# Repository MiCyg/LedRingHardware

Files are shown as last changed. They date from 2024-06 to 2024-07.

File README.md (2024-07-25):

# LedRingHardware

## Description

LedRingHardware is a simple PCB devBoard based on the RP2040 microcontroller, featuring 8 programmable LEDs and battery supply. This project was created to explore the capabilities of MicroPython and CircuitPython.

## Visualization
<p align="center">
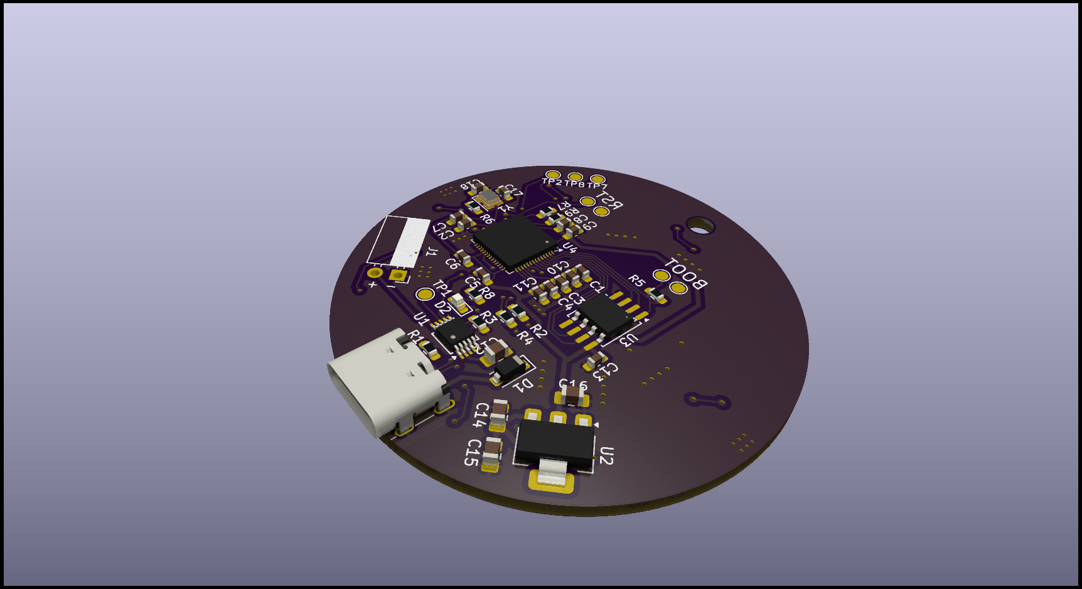
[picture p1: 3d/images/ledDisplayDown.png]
LED Display Bottom View
  
&nbsp; &nbsp; &nbsp; &nbsp;
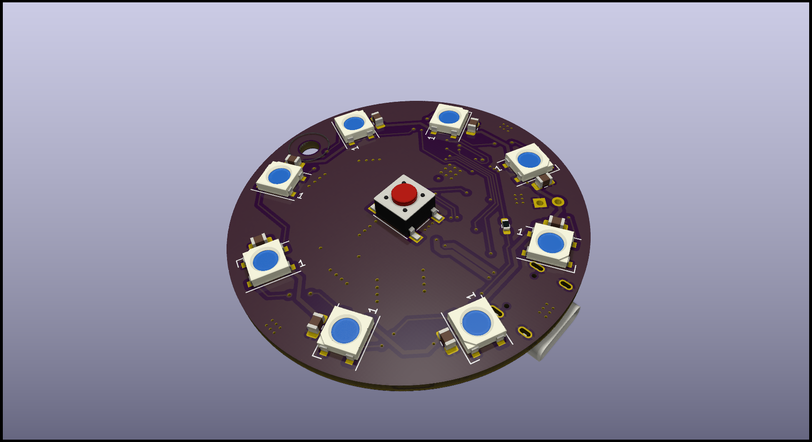
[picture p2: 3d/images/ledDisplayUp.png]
LED Display Top View
  
</p>

## Installation

- Enter to **BOOTSEL** mode connect **boot** testpoints placed close to **U3** chip.
- Download CircuitPython firmware for rp2040. There is avaliable [here](https://downloads.circuitpython.org/bin/raspberry_pi_pico/pl/adafruit-circuitpython-raspberry_pi_pico-pl-9.1.1.uf2) or for latest version go to [CircuitPython](https://circuitpython.org/) site.
- Copy `.uf2` firmware to device

## Example code

```python

import board
import time
import neopixel

LED_NUMBER = 8
BUTTON_PIN = board.GP22
LED_PIN = board.GP13

COLOR = (10,0,15)
disp_pix = neopixel.NeoPixel(LED_PIN, LED_NUMBER, auto_write=False)

while True:
	for i in range(LED_NUMBER):
		disp_pix[i] = COLOR
		disp_pix.show()
		time.sleep(0.1)
		
	for i in range(LED_NUMBER):
		disp_pix[i] = (0,0,0)
		disp_pix.show()
		time.sleep(0.1)
```

Expected results will be that:

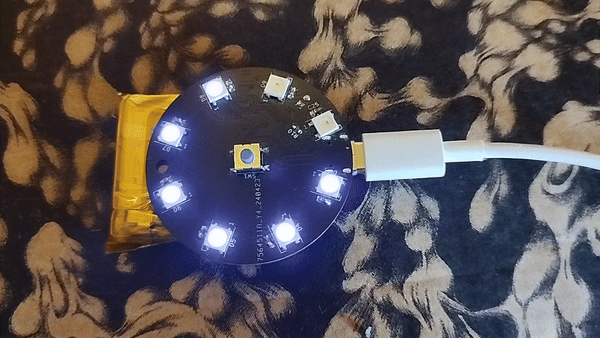
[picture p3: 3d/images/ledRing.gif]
LedRing working Example


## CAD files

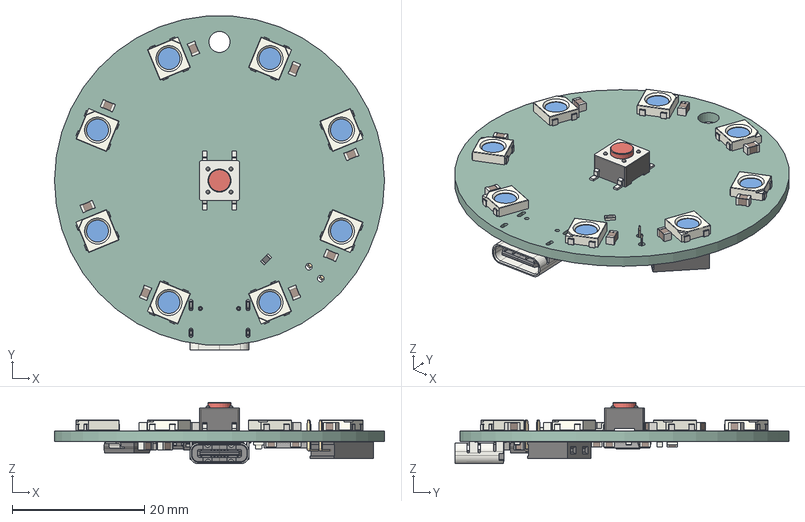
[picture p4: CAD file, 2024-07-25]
3d/ledDisplay.step
50.0 x 50.6 x 9.31 mm
C_0805_2012Metric x 12
LED_WS2812B_PLCC4_50x50mm_P32mm x 8
SW_SPST_PTS645
R_0603_1608Metric x 10
C_0603_1608Metric x 14
Crystal_SMD_2520-4Pin_2.5x2.0mm
MSOP_10_3x3mm_P05mm
HTSOP_8_1EP_39x49mm_Pitch127mm
LED_0603_1608Metric
D_SOD_123
PinSocket_1x02_P254mm_Horizontal
SOT_223
USB_C_Receptacle_16P_TopMnt_Horizontal_GCT_USB4105-xx-A
QFN_56_1EP_7x7mm_P04mm_EP32x32mm
ledDisplay_PCB

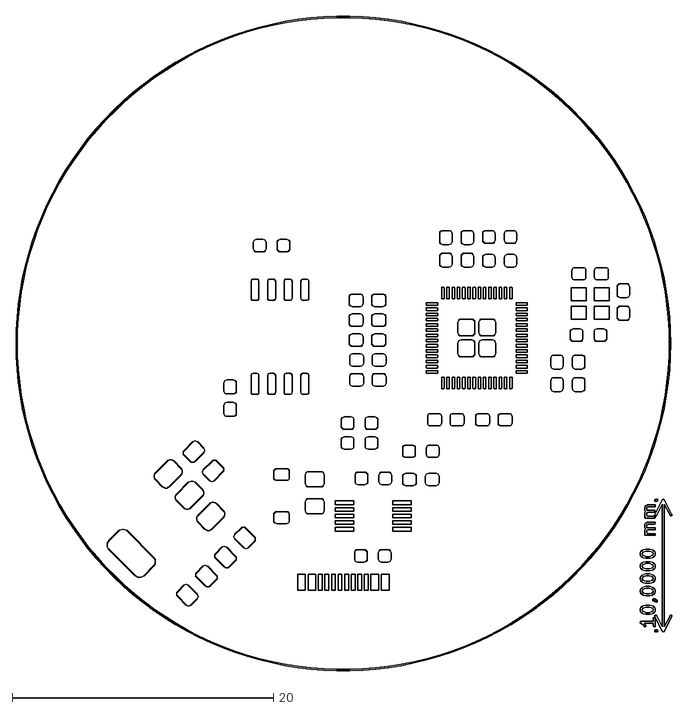
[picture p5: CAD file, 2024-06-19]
gerber/mask/ledDisplay-Edge_Cuts.dxf
50.2 x 50.1

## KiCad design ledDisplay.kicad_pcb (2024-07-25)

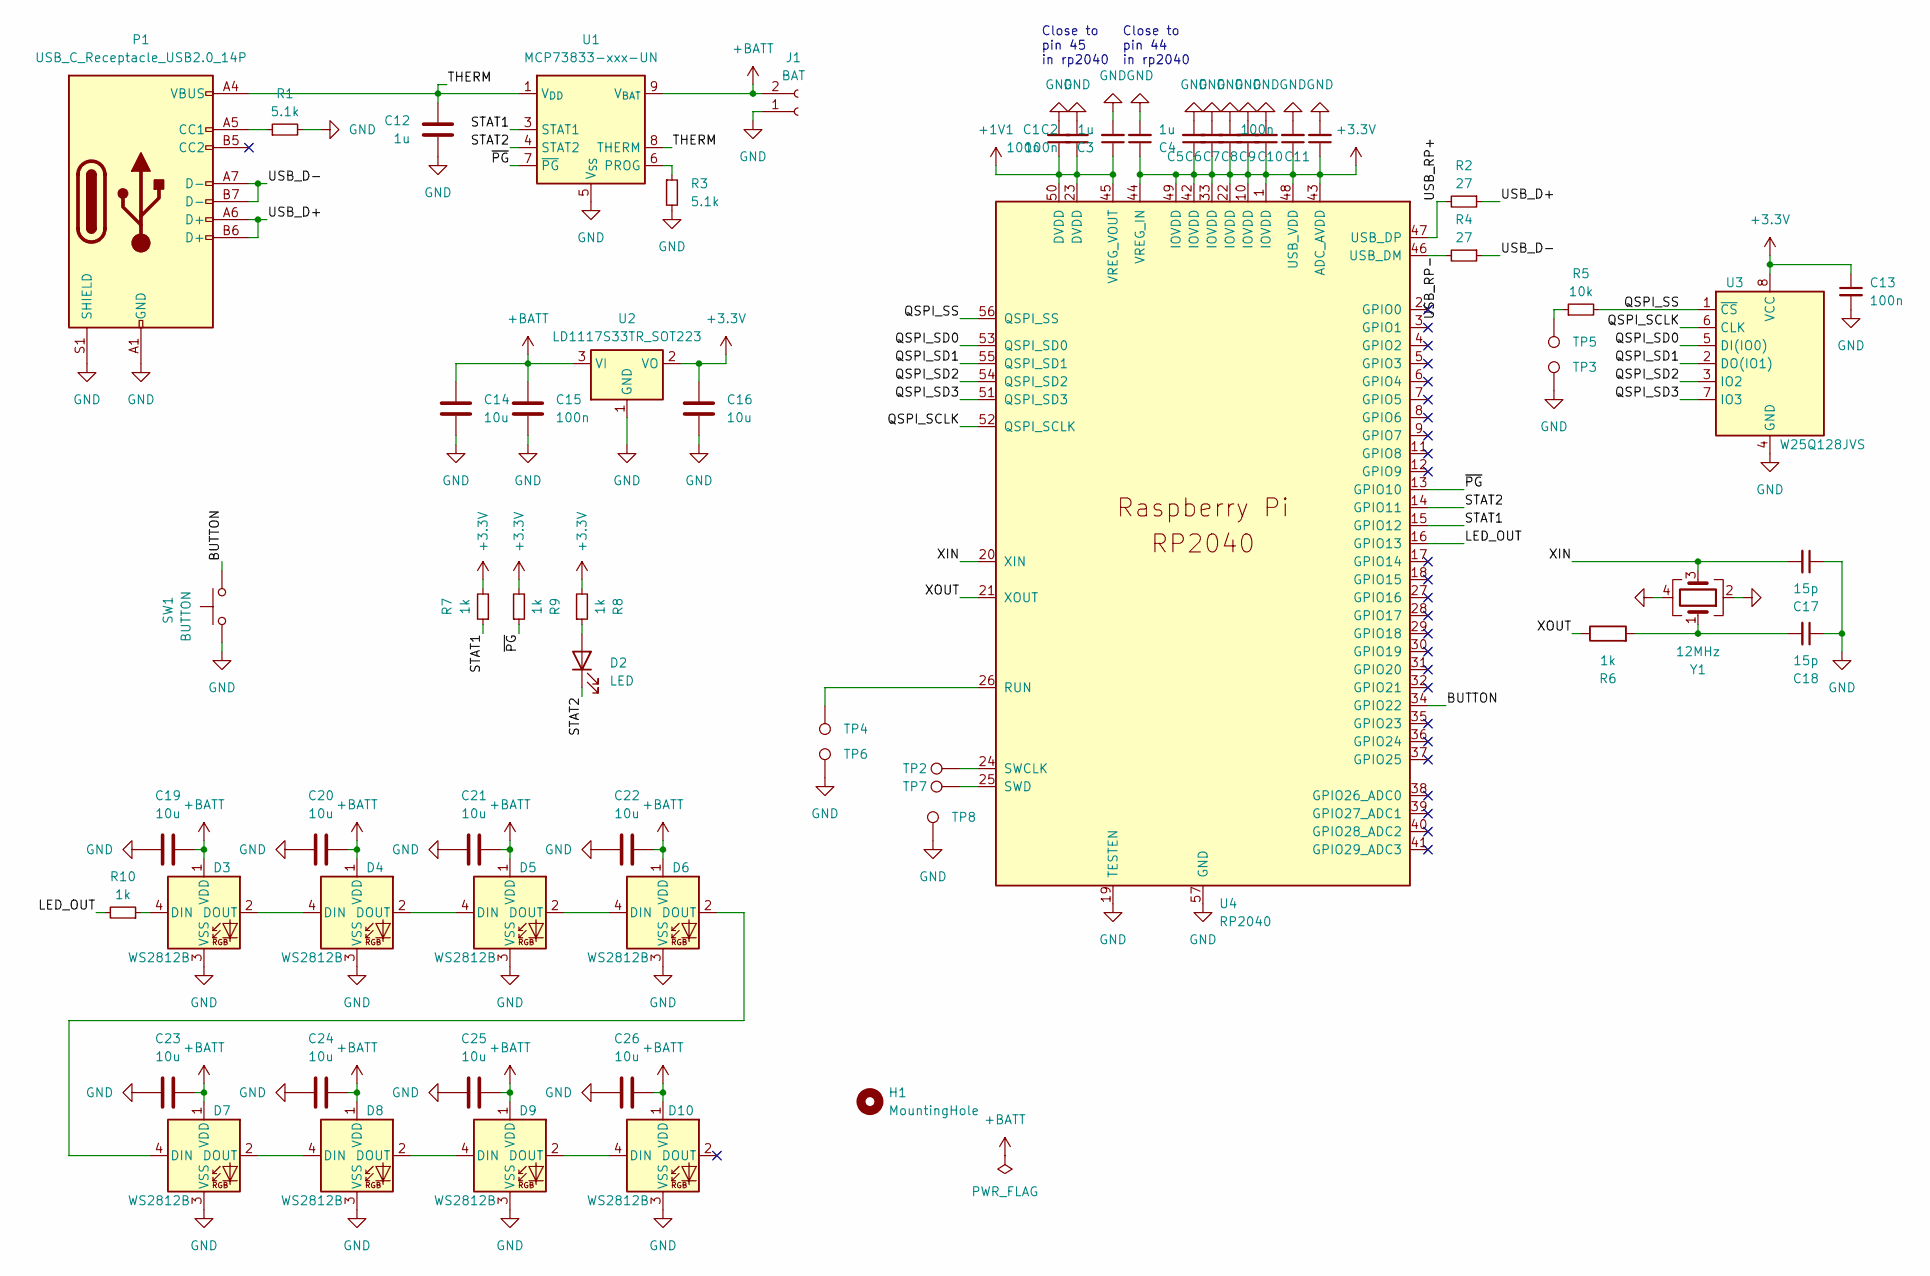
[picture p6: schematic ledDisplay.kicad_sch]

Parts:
C1, C2, C5, C6, C7, C8, C9, C10, C11, C13: 100n; C_0603_1608Metric_Pad1.08x0.95mm_HandSolder
C3, C4: 1u; C_0603_1608Metric_Pad1.08x0.95mm_HandSolder
C12: 1u; C_0805_2012Metric_Pad1.18x1.45mm_HandSolder
C14, C16, C19, C20, C21, C22, C23, C24, C25, C26: 10u; C_0805_2012Metric_Pad1.18x1.45mm_HandSolder
C15: 100n; C_0805_2012Metric_Pad1.18x1.45mm_HandSolder
C17, C18: 15p; C_0603_1608Metric_Pad1.08x0.95mm_HandSolder
D2: LED; LED_0603_1608Metric_Pad1.05x0.95mm_HandSolder
D3, D4, D5, D6, D7, D8, D9, D10: WS2812B; LED_WS2812B_PLCC4_5.0x5.0mm_P3.2mm
H1: MountingHole; MountingHole_3.2mm_M3
J1: BAT; PinSocket_1x02_P2.54mm_Horizontal
P1: USB_C_Receptacle_USB2.0_14P; USB_C_Receptacle_G-Switch_GT-USB-7010ASV
R1, R3: 5.1k; R_0603_1608Metric_Pad0.98x0.95mm_HandSolder
R2, R4: 27; R_0603_1608Metric_Pad0.98x0.95mm_HandSolder
R5: 10k; R_0603_1608Metric_Pad0.98x0.95mm_HandSolder
R6, R7, R8, R9, R10: 1k; R_0603_1608Metric_Pad0.98x0.95mm_HandSolder
SW1: BUTTON; SW_Push_1P1T_NO_6x6mm_H9.5mm
TP2, TP3, TP4, TP5, TP6, TP7, TP8: TestPoint; TestPoint_Pad_D1.5mm
U1: MCP73833-xxx-UN; MSOP-10_3x3mm_P0.5mm
U2: LD1117S33TR_SOT223; SOT-223-3_TabPin2
U3: W25Q128JVS; SOIC-8_5.23x5.23mm_P1.27mm
U4: RP2040; RP2040-QFN-56
Y1: 12MHz; Crystal_SMD_SeikoEpson_TSX3225-4Pin_3.2x2.5mm_HandSoldering

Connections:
+1V1: C1.1, C2.1, C3.1, U4.23 (DVDD), U4.45 (VREG_VOUT), U4.50 (DVDD)
+3.3V: C4.1, C5.1, C6.1, C7.1, C8.1, C9.1, C10.1, C11.1, C13.1, C16.1, R7.2, R8.2, R9.2, U2.2 (VO), U3.8 (VCC), U4.1 (IOVDD), U4.10 (IOVDD), U4.22 (IOVDD), U4.33 (IOVDD), U4.42 (IOVDD), U4.43 (ADC_AVDD), U4.44 (VREG_IN), U4.48 (USB_VDD), U4.49 (IOVDD)
+BATT: C14.1, C15.1, C19.1, C20.1, C21.1, C22.1, C23.1, C24.1, C25.1, C26.1, D3.1 (VDD), D4.1 (VDD), D5.1 (VDD), D6.1 (VDD), D7.1 (VDD), D8.1 (VDD), D9.1 (VDD), D10.1 (VDD), J1.2, U1.9 (V_{BAT}), U1.10 (V_{BAT}), U2.3 (VI)
/BUTTON: SW1.1, U4.34 (GPIO22)
/LED_OUT: R10.2, U4.16 (GPIO13)
/QSPI_SCLK: U3.6 (CLK), U4.52 (QSPI_SCLK)
/QSPI_SD0: U3.5 (DI(IO0)), U4.53 (QSPI_SD0)
/QSPI_SD1: U3.2 (DO(IO1)), U4.55 (QSPI_SD1)
/QSPI_SD2: U3.3 (IO2), U4.54 (QSPI_SD2)
/QSPI_SD3: U3.7 (IO3), U4.51 (QSPI_SD3)
/QSPI_SS: R5.2, U3.1 (~CS), U4.56 (QSPI_SS)
/STAT1: R7.1, U1.3 (STAT1), U4.15 (GPIO12)
/STAT2: D2.1 (K), U1.4 (STAT2), U4.14 (GPIO11)
/THERM: C12.1, P1.A4 (VBUS), P1.A9 (VBUS), P1.B4 (VBUS), P1.B9 (VBUS), U1.1 (V_{DD}), U1.2 (V_{DD}), U1.8 (THERM)
/USB_D+: P1.A6 (D+), P1.B6 (D+), R2.1
/USB_D-: P1.A7 (D-), P1.B7 (D-), R4.1
/USB_RP+: R2.2, U4.47 (USB_DP)
/USB_RP-: R4.2, U4.46 (USB_DM)
/XIN: C17.2, U4.20 (XIN), Y1.3
/XOUT: R6.1, U4.21 (XOUT)
/~PG: R9.1, U1.7 (~PG), U4.13 (GPIO10)
GND: C1.2, C2.2, C3.2, C4.2, C5.2, C6.2, C7.2, C8.2, C9.2, C10.2, C11.2, C12.2, C13.2, C14.2, C15.2, C16.2, C17.1, C18.1, C19.2, C20.2, C21.2, C22.2, C23.2, C24.2, C25.2, C26.2, D3.3 (VSS), D4.3 (VSS), D5.3 (VSS), D6.3 (VSS), D7.3 (VSS), D8.3 (VSS), D9.3 (VSS), D10.3 (VSS), J1.1, P1.A1 (GND), P1.A12 (GND), P1.B1 (GND), P1.B12 (GND), P1.S1 (SHIELD), R1.2, R3.2, SW1.2, TP3.1, TP6.1, TP8.1, U1.5 (V_{SS}), U2.1 (GND), U3.4 (GND), U4.19 (TESTEN), U4.57 (GND), Y1.2, Y1.4
unnamed: C18.2, R6.2, Y1.1
unnamed: D2.2 (A), R8.1
unnamed: D3.4 (DIN), R10.1
unnamed: D3.2 (DOUT), D4.4 (DIN)
unnamed: D4.2 (DOUT), D5.4 (DIN)
unnamed: D5.2 (DOUT), D6.4 (DIN)
unnamed: D6.2 (DOUT), D7.4 (DIN)
unnamed: D7.2 (DOUT), D8.4 (DIN)
unnamed: D8.2 (DOUT), D9.4 (DIN)
unnamed: D9.2 (DOUT), D10.4 (DIN)
unnamed: P1.A5 (CC1), R1.1
unnamed: R5.1, TP5.1
unnamed: R3.1, U1.6 (PROG)
unnamed: TP4.1, U4.26 (RUN)
unnamed: TP2.1, U4.24 (SWCLK)
unnamed: TP7.1, U4.25 (SWD)

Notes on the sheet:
Close to pin 45 in rp2040
Close to pin 44 in rp2040

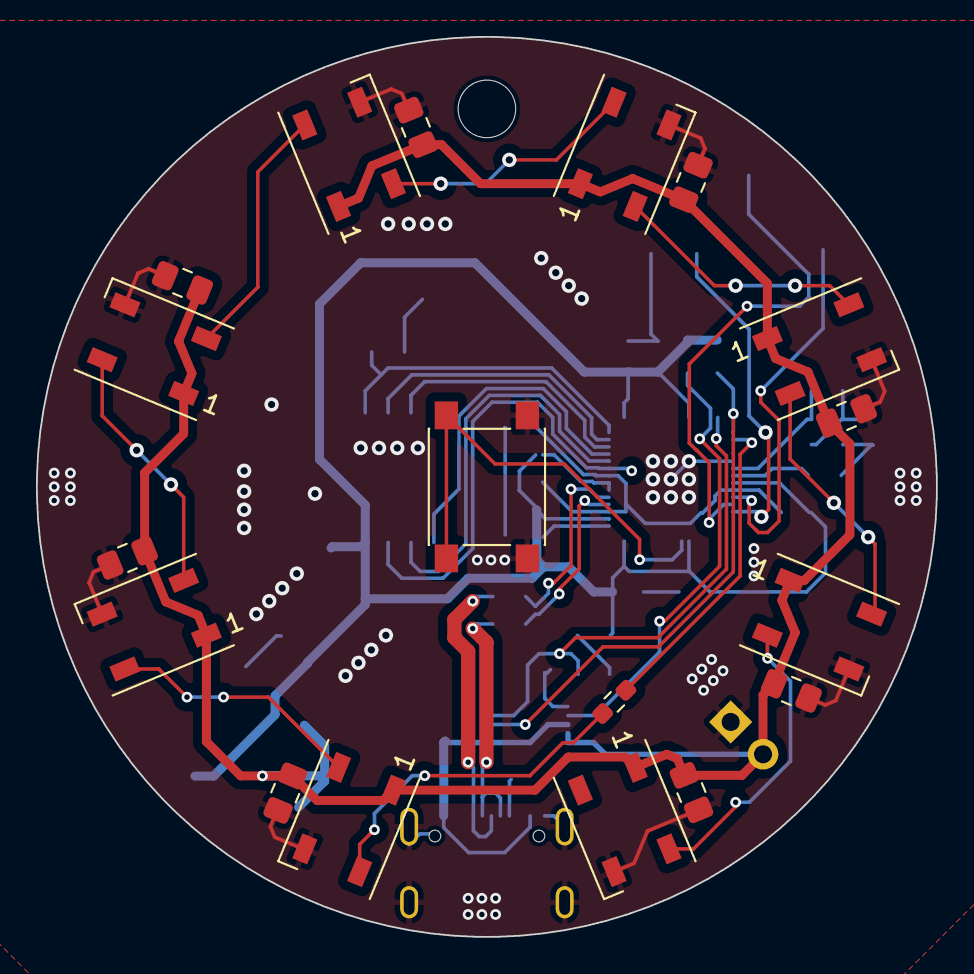
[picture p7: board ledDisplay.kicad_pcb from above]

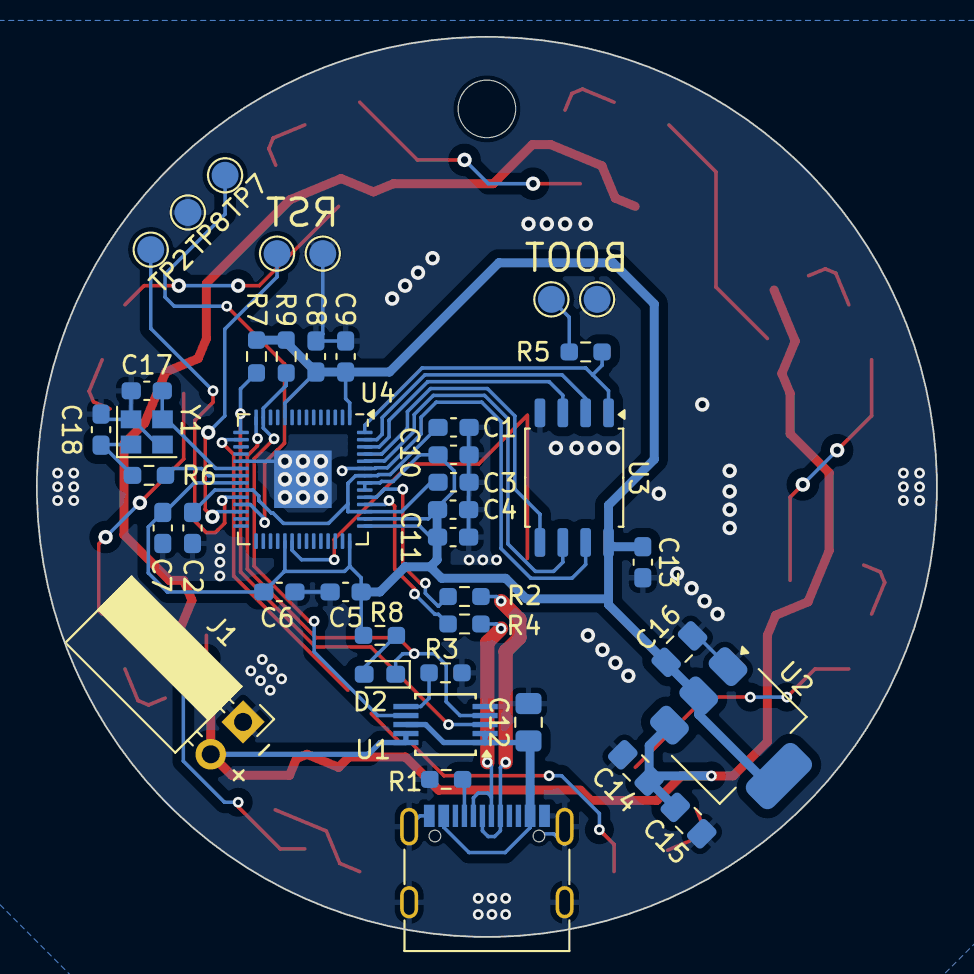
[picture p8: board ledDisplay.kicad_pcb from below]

Board: 2 copper layers, 50.0 x 50.0 mm, 61 parts (42 on the bottom side), 38 nets.

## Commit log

2024-06-20 add step file
    [ledDisplay.kicad_pcb, ledDisplay.step]
2024-07-25 change PCB descriptions
    [ledDisplay.kicad_pcb, ledDisplay.step]
2024-07-25 update pcb
    [ledDisplay.kicad_pcb, ledDisplay.kicad_sch]
